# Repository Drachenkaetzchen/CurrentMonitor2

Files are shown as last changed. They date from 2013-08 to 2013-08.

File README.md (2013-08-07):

Design Goals
============

The measurement limits are:
0-60V with 1mV resolution
0-30A with 1mA resolution

Power Input
===========

We accept two different power sources: Power from the device under test and an external power supply.

To reduce the part count we're using the LM2591HV simple switcher for powering via the device under test
or via an external power supply and an LTC4412 to switch over between the 5V rails.

Having two step-down DC converters might seem to be overkill, but I wasn't able to find an easy power
switching device which supports up to 60V which is required for the measurement input, so switching
two separate 5V rails seems to be convinient for now.

Drawbacks
=========

- We will have marginally wrong readings if powering the meter via the device under test. This needs to
  be fixed, because our current draw isn't constant (especially with the WiFi module).

Shunt Resistor Considerations
=============================

The full-scale output of the shunt resistor must be between 50mV and 100mV for optimal performance. For
30A and 0.1V voltage drop, this gives us:

R=U/I
R=0.1/30
R=0.003 (nearest value)

Dale WSL3637 was chosen due to the low cost and eagle library availability.

Cable Connector Considerations
==============================

The Connector needs to widthstand 30A, and the Phoenix Contact MKDS 5/ 2-6,35 can support up to 32A.

LCD
===
For the initial design, we're using an industry standard LCD. I'm not sure how well this works and how
interchangeable different LCDs are, or if I need to stick to a specific manufacturer.

modbus rs485?
rtc?

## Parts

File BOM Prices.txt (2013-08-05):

1	SI2309CDS		0,267	0,267
1	INA168			1,75		1,75
2	AKL701			1,16		2,32
1	WSL36373L000FEB	0,83		0,83
1	Z-DIODE 10V		0,13		0,13
1	ATMEGA168		2,37		2,37
1	LCD				7		7
1	N CHANNEL MOS	0,23		0,23
1	ISP				0,20		0,20
1	MAX3232CWE		3,46		3,46
1	CRYSTAL			0,42		0,42
1	PASSIVES			1		1

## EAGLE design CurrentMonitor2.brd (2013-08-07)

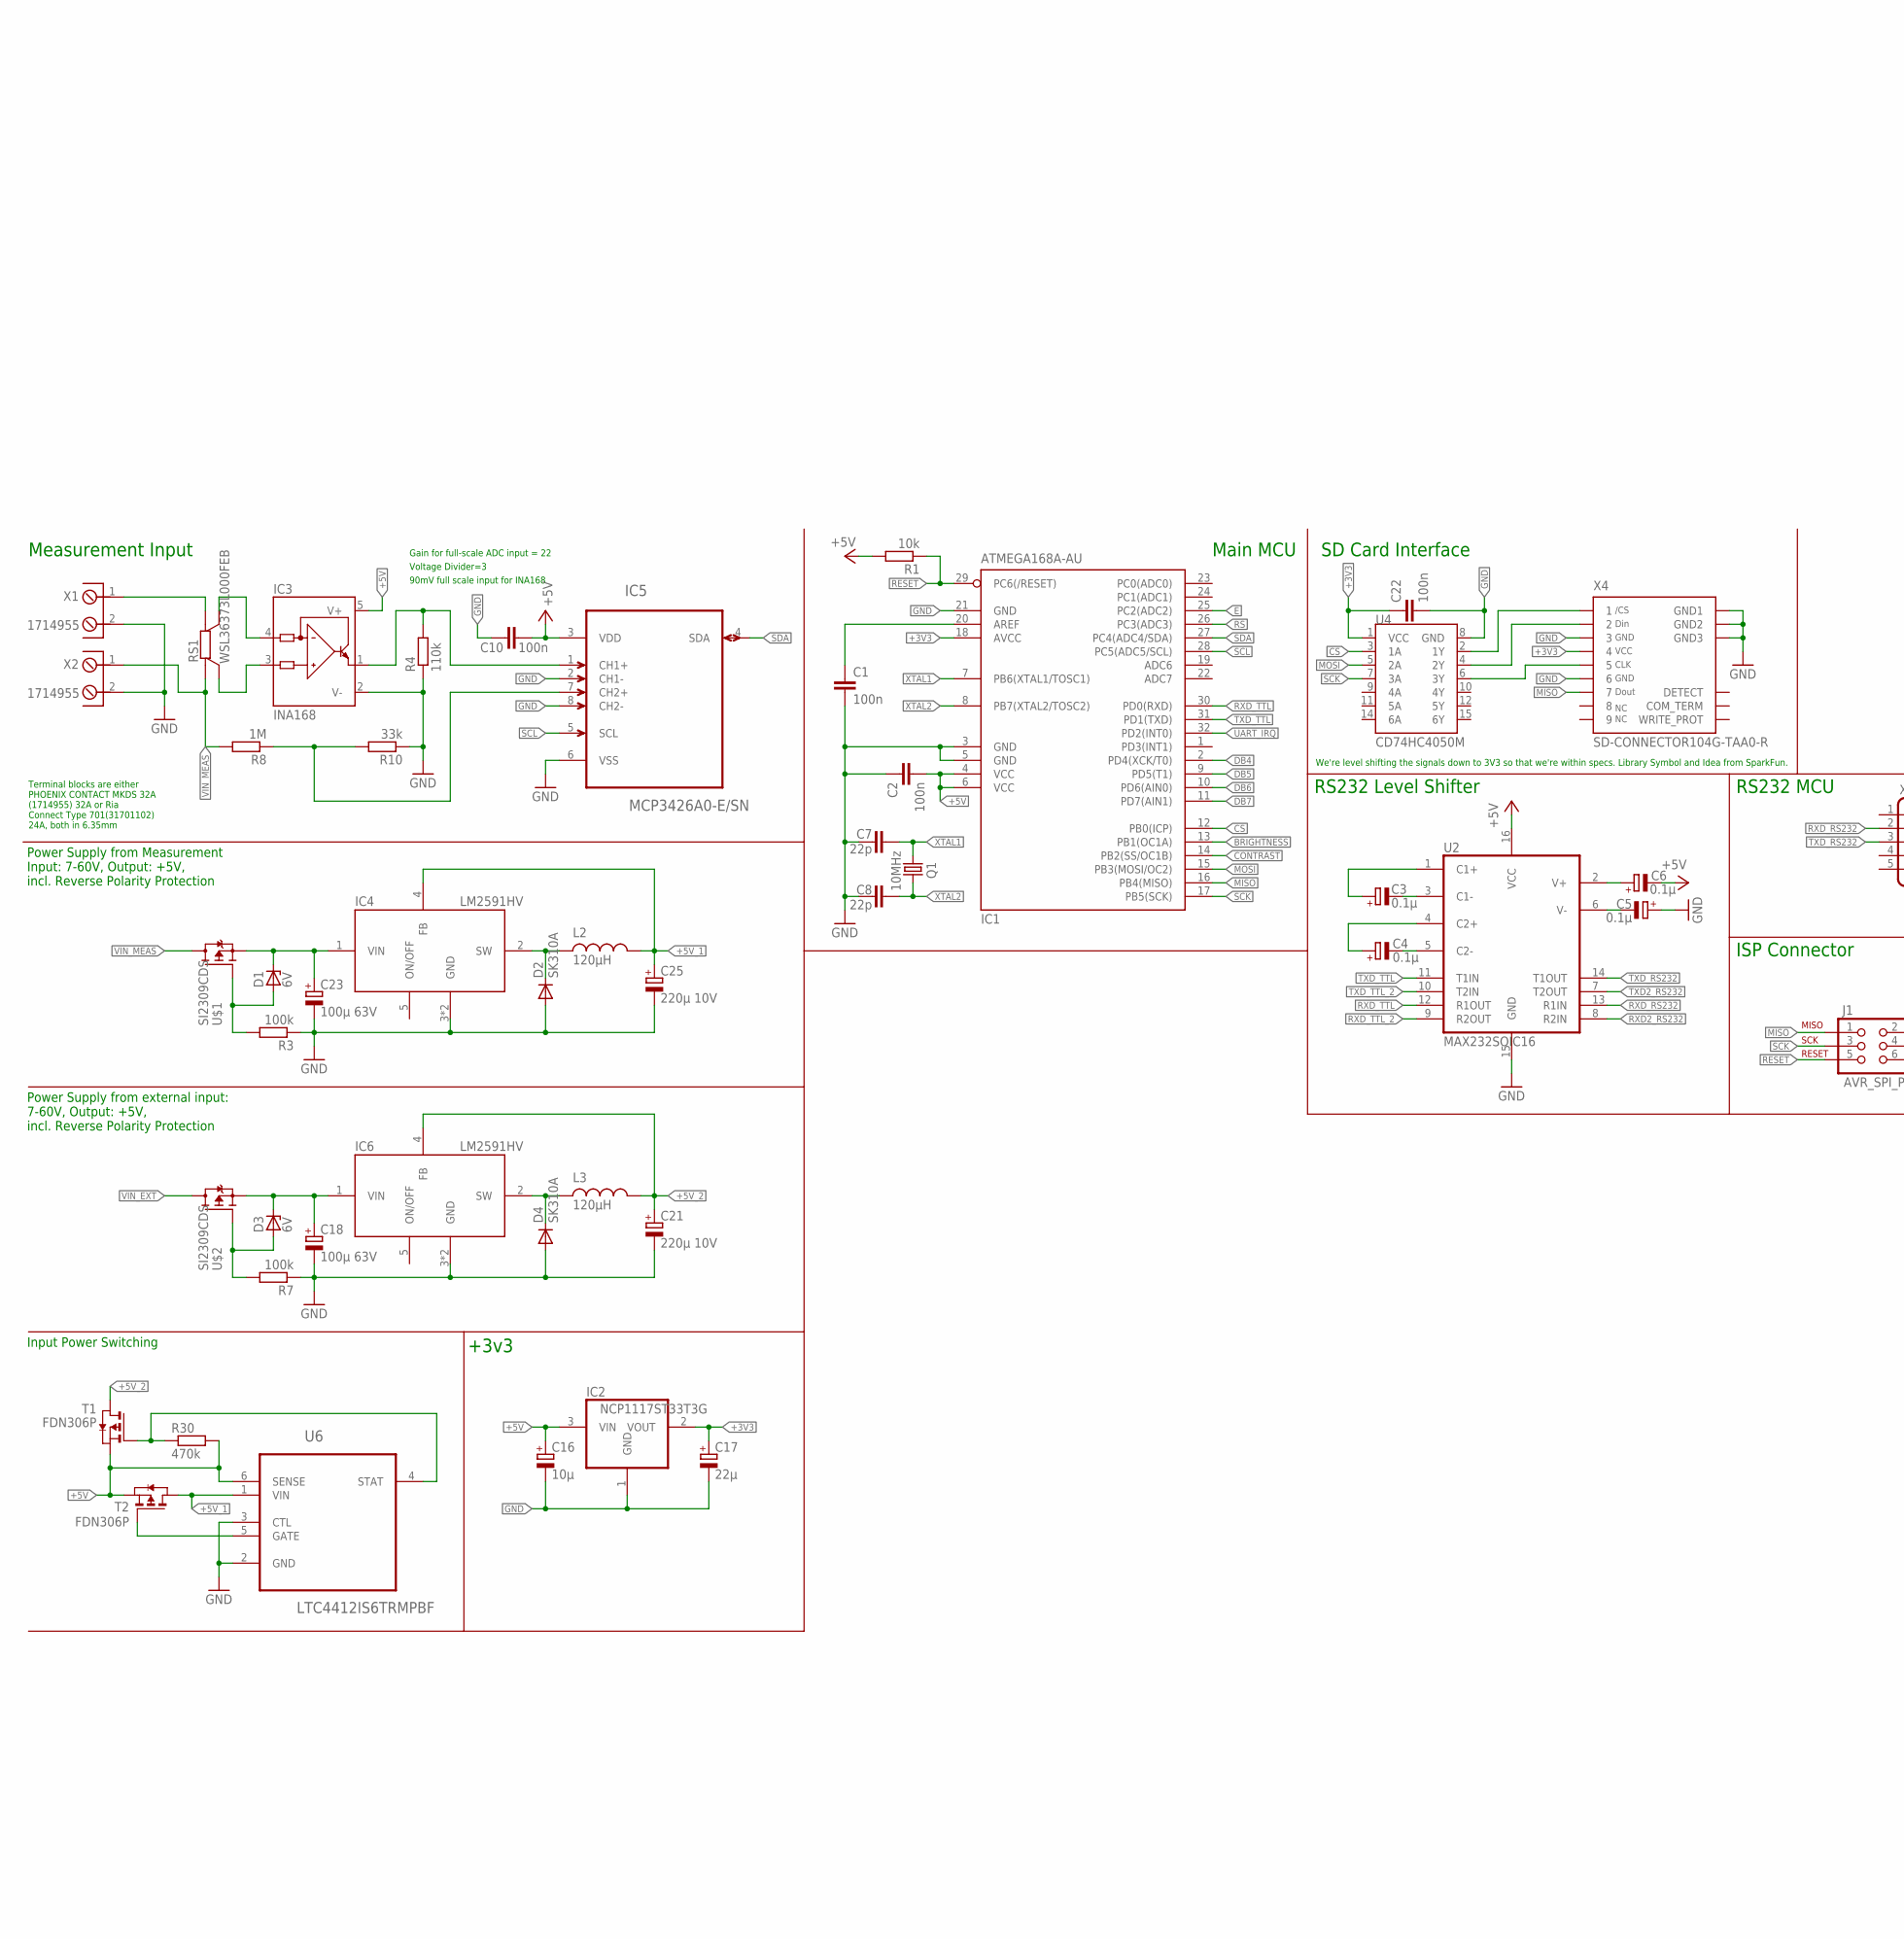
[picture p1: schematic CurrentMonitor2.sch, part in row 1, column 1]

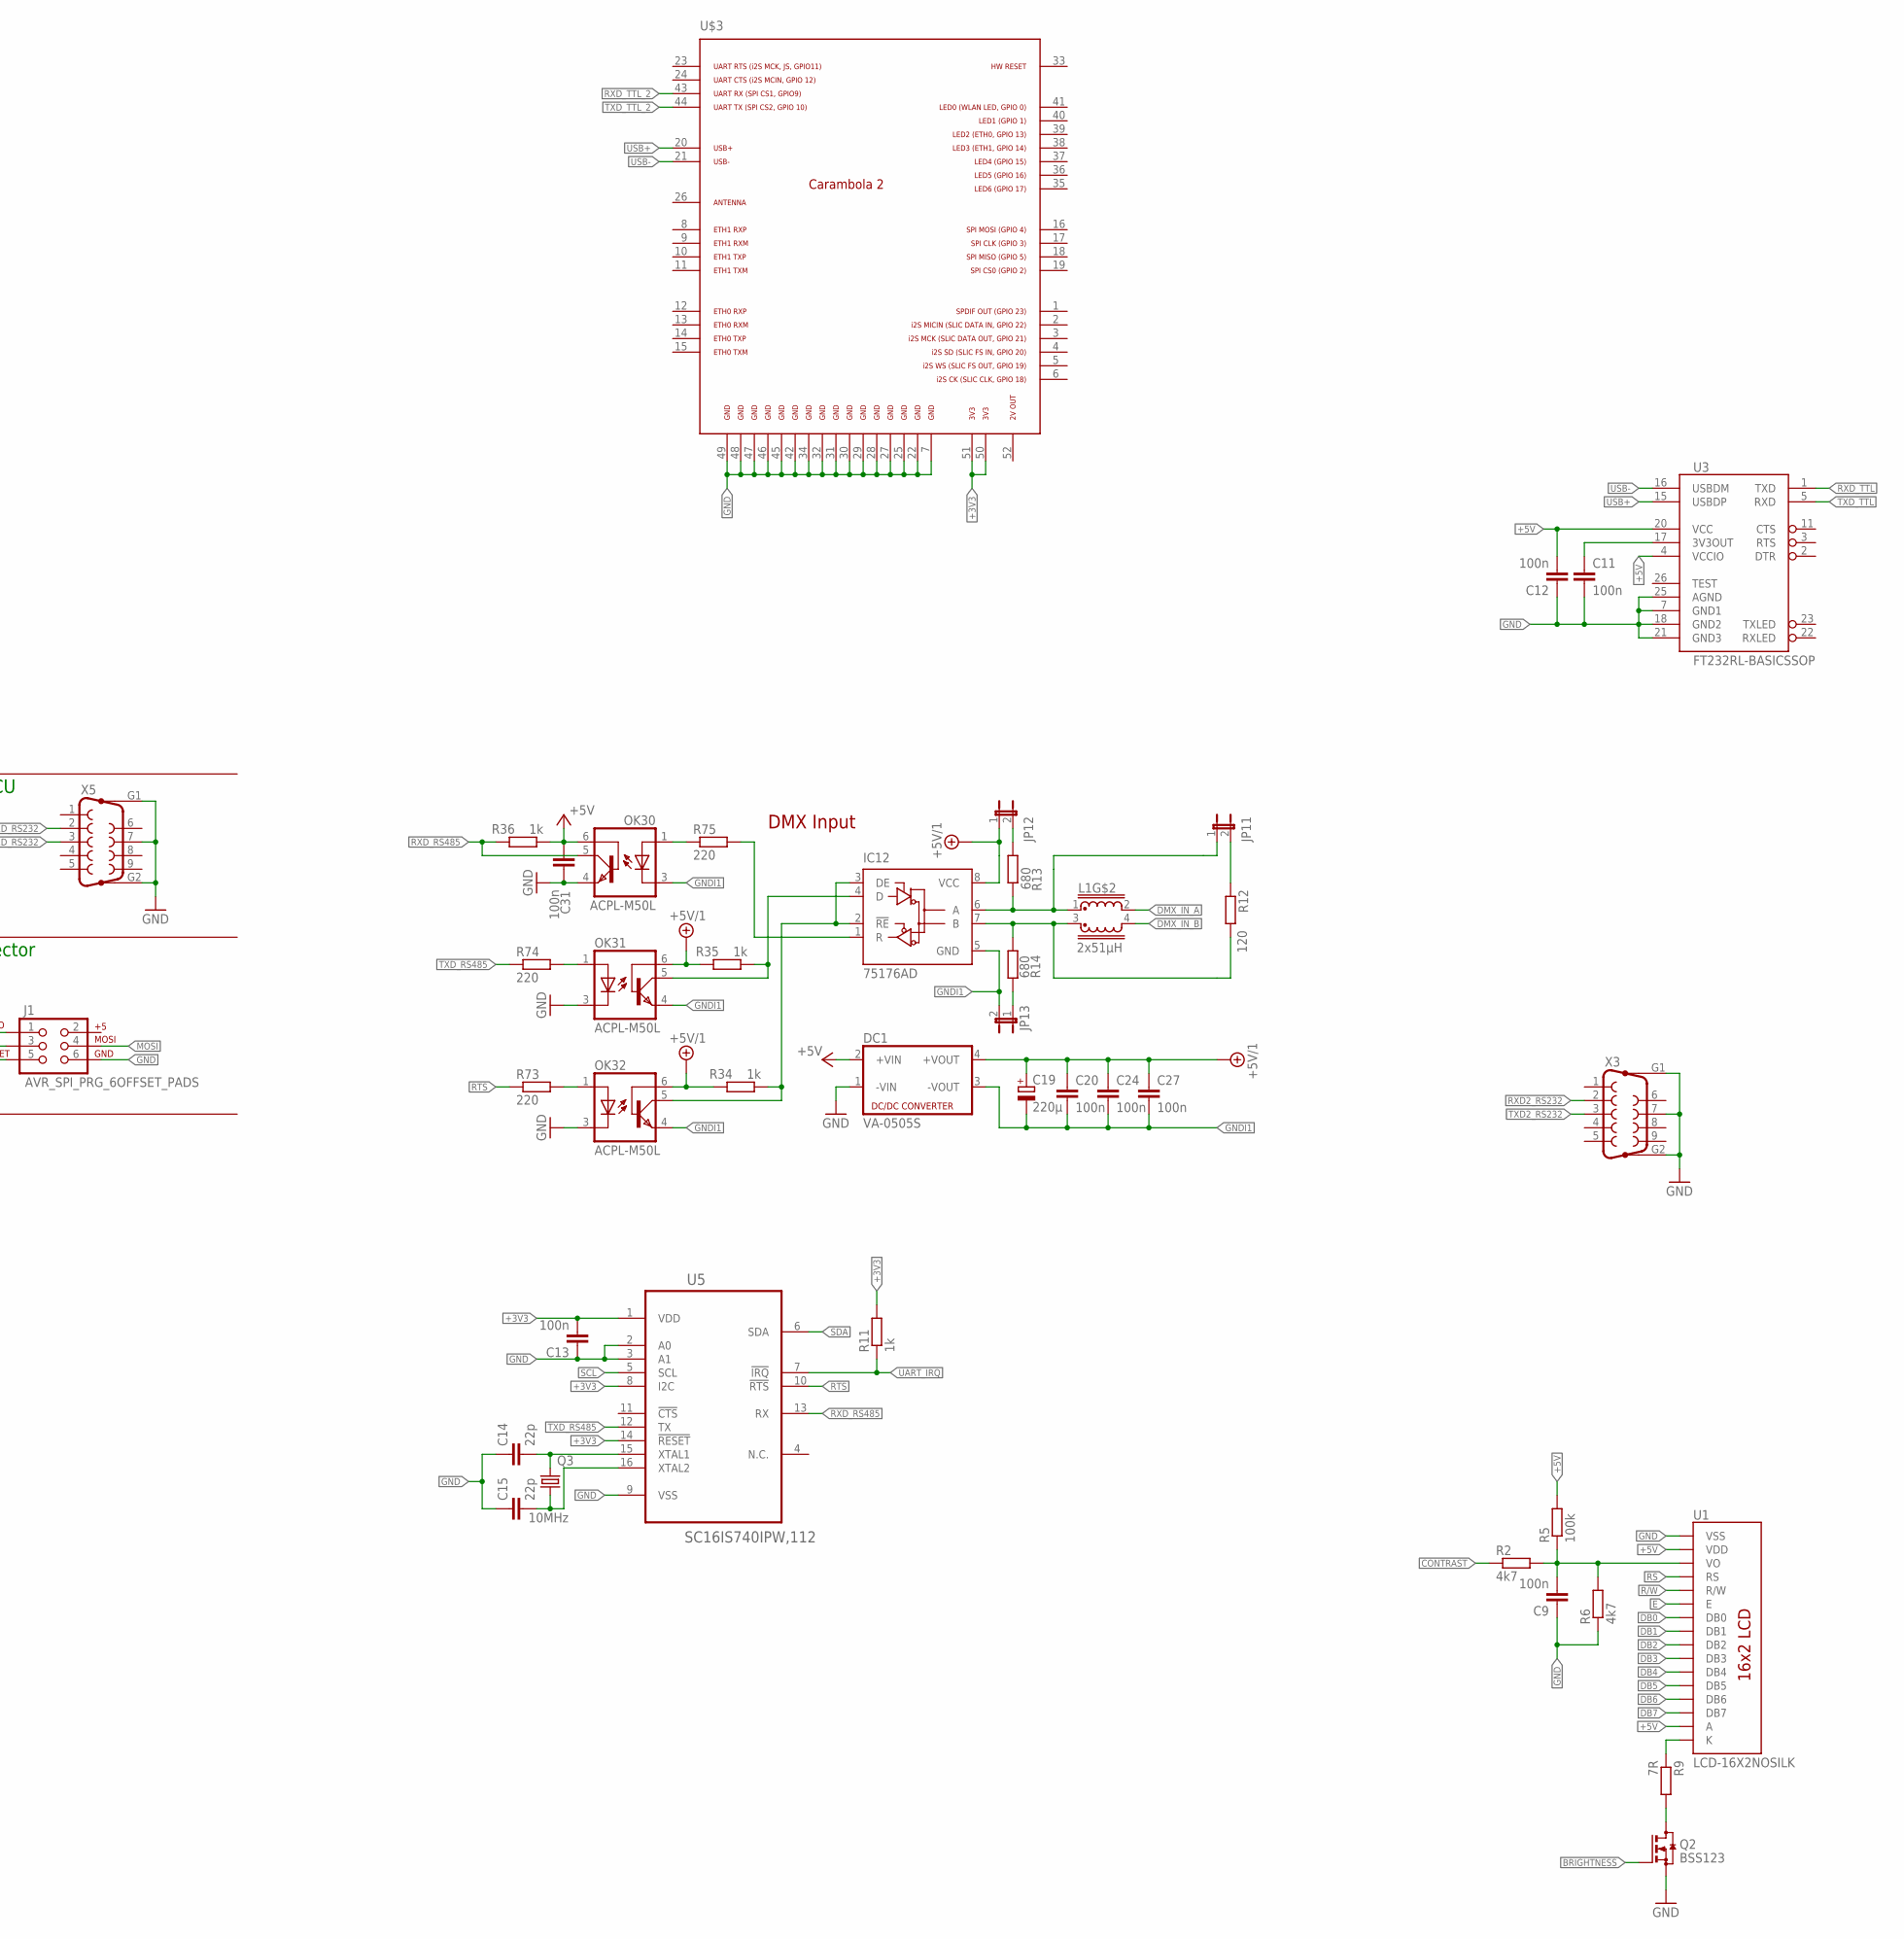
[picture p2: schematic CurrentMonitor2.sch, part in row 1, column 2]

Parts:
C1, C2, C9, C10, C11, C12, C13, C20, C22, C24, C27, C31: 100n; C0805
C3, C4, C5, C6: 0.1µ; PANASONIC_B
C7, C8, C14, C15: 22p; C0805
C16: 10µ; PANASONIC_B
C17: 22µ; PANASONIC_B
C18, C23: 100µ 63V; PANASONIC_G
C19: 220µ; PANASONIC_D
C21, C25: 220µ 10V; PANASONIC_D
D1, D3: 6V; SOT23
D2, D4: SK310A; DO214AC
DC1: VA-0505S; 4SIL
IC1: ATMEGA168A-AU; TQFP32-08
IC2: NCP1117ST33T3G; SOT223
IC3: INA168; SOT23-5
IC4, IC6: LM2591HV; TO263-5
IC5: MCP3426A0-E/SN; SOIC127P600X175-8N
IC12: 75176AD; D_R-PDSO-G8
J1: AVR_SPI_PRG_6OFFSET_PADS; 2X3_OFFSET
JP11, JP12, JP13: JP1E; JP1
L1: 2x51µH; EPCOS_B82790_SERIES
L2, L3: 120µH; MSS1260
OK30, OK31, OK32: ACPL-M50L; JEDEC_MS-012-AA_SOIC5
Q1, Q3: 10MHz; HC49UP
Q2: BSS123; SOT23
R1: 10k; R0805
R2, R6: 4k7; R0805
R3, R5, R7: 100k; R0805
R4: 110k; R0805
R8: 1M; R0805
R9: 7R; R0805
R10: 33k; R0805
R11, R34, R35, R36: 1k; R0805
R12: 120; R0805
R13, R14: 680; R0805
R30: 470k; R0805
R73, R74, R75: 220; R0805
RS1: WSL36373L000FEB; CSM3637M
T1, T2: FDN306P; SOT-23
U1: LCD-16X2NOSILK; LCD-16X2_NOSILK
U2: MAX232SOIC16; SO016
U3: FT232RL-BASICSSOP; SSOP28DB
U4: CD74HC4050M; SO016
U5: SC16IS740IPW,112; SOP65P640X110-16N
U6: LTC4412IS6TRMPBF; SOT95P280X100-6N
U$1, U$2: SI2309CDS; SOT23
U$3: CARAMBOLA2
X1, X2: 1714955; AKL701_2_13
X3, X5: F09HP
X4: SD-CONNECTOR104G-TAA0-R; 104G-TAA0-R

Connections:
+3V3: C1.1, C13.2, C17.+, C22.1, IC1.18 (AVCC), IC1.20 (AREF), IC2.2 (VOUT), R11.2, U4.1 (VCC), U5.1 (VDD), U5.8 (I2C), U5.14 (!RESET), U$3.50, U$3.51, X4.4
+5V: C2.2, C6.-, C10.1, C12.2, C16.+, C31.1, DC1.2 (+VIN), IC1.4 (VCC), IC1.6 (VCC), IC2.3 (VIN), IC3.5 (V+), IC5.3 (VDD), OK30.6 (BAS), R1.2, R5.2, R30.2, R36.1, T1.2 (S), T2.2 (S), U1.2 (VDD), U1.15 (A), U2.16 (VCC), U3.4 (VCCIO), U3.20 (VCC), U6.6 (SENSE)
+5V_1: C25.+, IC4.4 (FB), L2.P$1, T2.1 (D), U6.1 (VIN)
+5V_2: C21.+, IC6.4 (FB), L3.P$1, T1.1 (D)
ADC0: IC3.1 (OUT), IC5.1 (CH1+), R4.2
ADC1: IC5.7 (CH2+), R8.1, R10.2
BRIGHTNESS: IC1.13 (PB1(OC1A)), Q2.1 (G)
CONTRAST: IC1.14 (PB2(SS/OC1B)), R2.1
CS: IC1.12 (PB0(ICP)), U4.3 (1A)
DB0: U1.7 (DB0)
DB1: U1.8 (DB1)
DB2: U1.9 (DB2)
DB3: U1.10 (DB3)
DB4: IC1.2 (PD4(XCK/T0)), U1.11 (DB4)
DB5: IC1.9 (PD5(T1)), U1.12 (DB5)
DB6: IC1.10 (PD6(AIN0)), U1.13 (DB6)
DB7: IC1.11 (PD7(AIN1)), U1.14 (DB7)
DMX_IN_A: L1.2 (4)
DMX_IN_B: L1.4
E: IC1.25 (PC2(ADC2)), U1.6 (E)
GND: C1.2, C2.1, C5.+, C7.1, C8.1, C9.1, C10.2, C11.2, C12.1, C13.1, C14.1, C15.1, C16.-, C17.-, C18.-, C21.-, C22.2, C23.-, C25.-, C31.2, D2.A, D4.A, DC1.1 (-VIN), IC1.3 (GND), IC1.5 (GND), IC1.21 (GND), IC2.1 (GND), IC3.2 (V-), IC4.3 (GND), IC4.6 (GND), IC5.2 (CH1-), IC5.6 (VSS), IC5.8 (CH2-), IC6.3 (GND), IC6.6 (GND), J1.6, OK30.4 (EMI), OK31.3 (C), OK32.3 (C), Q2.2 (S), R3.1, R4.1, R6.1, R7.1, R10.1, U1.1 (VSS), U2.15 (GND), U3.7 (GND1), U3.18 (GND2), U3.21 (GND3), U3.25 (AGND), U4.8 (GND), U5.2 (A0), U5.3 (A1), U5.9 (VSS), U6.2 (GND), U6.3 (CTL), U$3.7, U$3.22, U$3.25, U$3.27, U$3.28, U$3.29, U$3.30, U$3.31, U$3.32, U$3.34, U$3.42, U$3.45, U$3.46, U$3.47, U$3.48, U$3.49, X1.2, X2.2, X3.7, X3.G1, X3.G2, X4.3, X4.6, X4.GND1, X4.GND2, X4.GND3, X5.7, X5.G1, X5.G2
GNDI1: C19.-, C20.2, C24.2, C27.2, DC1.3 (-VOUT), IC12.5 (GND), JP13.2, OK30.3 (C), OK31.4 (EMI), OK32.4 (EMI)
MISO: IC1.16 (PB4(MISO)), J1.1, X4.7
MOSI: IC1.15 (PB3(MOSI/OC2)), J1.4, U4.5 (2A)
unnamed: IC3.3 (IN+), RS1.S2
unnamed: IC3.4 (IN-), RS1.S1
unnamed: D3.1 (A), R7.2, U$2.1 (G)
unnamed: D1.1 (A), R3.2, U$1.1 (G)
unnamed: RS1.I1, X1.1
unnamed: C6.+, U2.2 (V+)
unnamed: D4.C, IC6.2 (SW), L3.P$2
unnamed: R30.1, T1.3 (G), U6.4 (STAT)
unnamed: C5.-, U2.6 (V-)
unnamed: D2.C, IC4.2 (SW), L2.P$2
unnamed: C3.-, U2.3 (C1-)
unnamed: C4.-, U2.5 (C2-)
unnamed: C4.+, U2.4 (C2+)
unnamed: C3.+, U2.1 (C1+)
unnamed: T2.3 (G), U6.5 (GATE)
unnamed: Q2.3 (D), R9.2
unnamed: C11.1, U3.17 (3V3OUT)
unnamed: C14.2, Q3.2, U5.15 (XTAL1)
unnamed: C15.2, Q3.1, U5.16 (XTAL2)
unnamed: U4.2 (1Y), X4.1
unnamed: U4.4 (2Y), X4.2
unnamed: R9.1, U1.16 (K)
unnamed: U4.6 (3Y), X4.5
unnamed: IC12.6 (A), JP11.1, L1.1, R13.1
unnamed: JP12.2, R13.2
unnamed: JP13.1, R14.1
unnamed: JP11.2, R12.1
unnamed: IC12.7 (B), L1.3 (1), R12.2, R14.2
unnamed: OK30.1 (A), R75.1
unnamed: OK31.1 (A), R74.2
unnamed: OK32.1 (A), R73.2
R/W: U1.5 (R/W)
REC$1: IC12.1 (R), R75.2
RESET: IC1.29 (PC6(/RESET)), J1.5, R1.1
RE_OUT: IC12.2 (!RE), IC12.3 (DE), OK32.5 (COL), R34.1
RS: IC1.26 (PC3(ADC3)), U1.4 (RS)
RTS: R73.1, U5.10 (!RTS)
RXD2_RS232: U2.8 (R2IN), X3.2
RXD_RS232: U2.13 (R1IN), X5.2
RXD_RS485: OK30.5 (COL), R36.2, U5.13 (RX)
RXD_TTL: IC1.30 (PD0(RXD)), U2.12 (R1OUT), U3.1 (TXD)
RXD_TTL_2: U2.9 (R2OUT), U$3.43
SCK: IC1.17 (PB5(SCK)), J1.3, U4.7 (3A)
SCL: IC1.28 (PC5(ADC5/SCL)), IC5.5 (SCL), U5.5 (SCL)
SDA: IC1.27 (PC4(ADC4/SDA)), IC5.4 (SDA), U5.6 (SDA)
TXD2_RS232: U2.7 (T2OUT), X3.3
TXD_OUT: IC12.4 (D), OK31.5 (COL), R35.1
TXD_RS232: U2.14 (T1OUT), X5.3
TXD_RS485: R74.1, U5.12 (TX)
TXD_TTL: IC1.31 (PD1(TXD)), U2.11 (T1IN), U3.5 (RXD)
TXD_TTL_2: U2.10 (T2IN), U$3.44
UART_IRQ: IC1.32 (PD2(INT0)), R11.1, U5.7 (!IRQ)
USB+: U3.15 (USBDP), U$3.20
USB-: U3.16 (USBDM), U$3.21
VCCIO1: C19.+, C20.1, C24.1, C27.1, DC1.4 (+VOUT), IC12.8 (VCC), JP12.1, OK31.6 (BAS), OK32.6 (BAS), R34.2, R35.2
VIN: C23.+, D1.3 (C), IC4.1 (VIN), U$1.2 (S)
VIN1: C18.+, D3.3 (C), IC6.1 (VIN), U$2.2 (S)
VIN_EXT: U$2.3 (D)
VIN_MEAS: R8.2, RS1.I2, U$1.3 (D), X2.1
VO: C9.2, R2.2, R5.1, R6.2, U1.3 (VO)
XTAL1: C7.2, IC1.7 (PB6(XTAL1/TOSC1)), Q1.2
XTAL2: C8.2, IC1.8 (PB7(XTAL2/TOSC2)), Q1.1

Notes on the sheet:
Gain for full-scale ADC input = 22
Voltage Divider=3
Terminal blocks are either PHOENIX CONTACT MKDS 32A (1714955) 32A or Ria Connect Type 701(31701102) 24A, both in 6.35mm
90mV full scale input for INA168
DMX Input
Measurement Input
Main MCU
SD Card Interface
We're level shifting the signals down to 3V3 so that we're within specs. Library Symbol and Idea from SparkFun.
RS232 Level Shifter
RS232 MCU
ISP Connector
+3v3
Power Supply from Measurement Input: 7-60V, Output: +5V, incl. Reverse Polarity Protection
Power Supply from external input: 7-60V, Output: +5V, incl. Reverse Polarity Protection
Input Power Switching

Board: 2 copper layers, 90 parts (0 on the bottom side), 78 nets, no tracks yet.

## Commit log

2013-08-06 Added RS485 and WiFi options, finalized some parts of the design including order codes and prices @100pcs
    [CurrentMonitor2.brd, CurrentMonitor2.sch]
2013-08-07 Added dual input switching power supplies and power switching circuitry
    [CurrentMonitor2.brd, CurrentMonitor2.sch]

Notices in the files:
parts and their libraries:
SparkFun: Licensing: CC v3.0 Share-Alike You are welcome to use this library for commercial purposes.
